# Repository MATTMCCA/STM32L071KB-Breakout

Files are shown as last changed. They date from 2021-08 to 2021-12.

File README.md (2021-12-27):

# STM32L071KB-Breakout
 STM32L071KB Breakout/Eval Board & STLink V2 adapter.
 
*Was quickly thrown together to further private works.*

**Gerbers meet JLC design spec**
 
 ## BOM
* EVAL 

[Digikey Cart Share](https://www.digikey.com/short/h47hrp48)

[Board](https://oshpark.com/shared_projects/n7sNnrIe)

* PROG 

[Digikey Cart Share](https://www.digikey.com/short/nmdddnm9)

[Board](https://oshpark.com/shared_projects/kYvOD2Zq)

---
### Captains Log (star date.. too cloudy, can't tell)

Boards came back from fab, they look good, just waiting on parts....

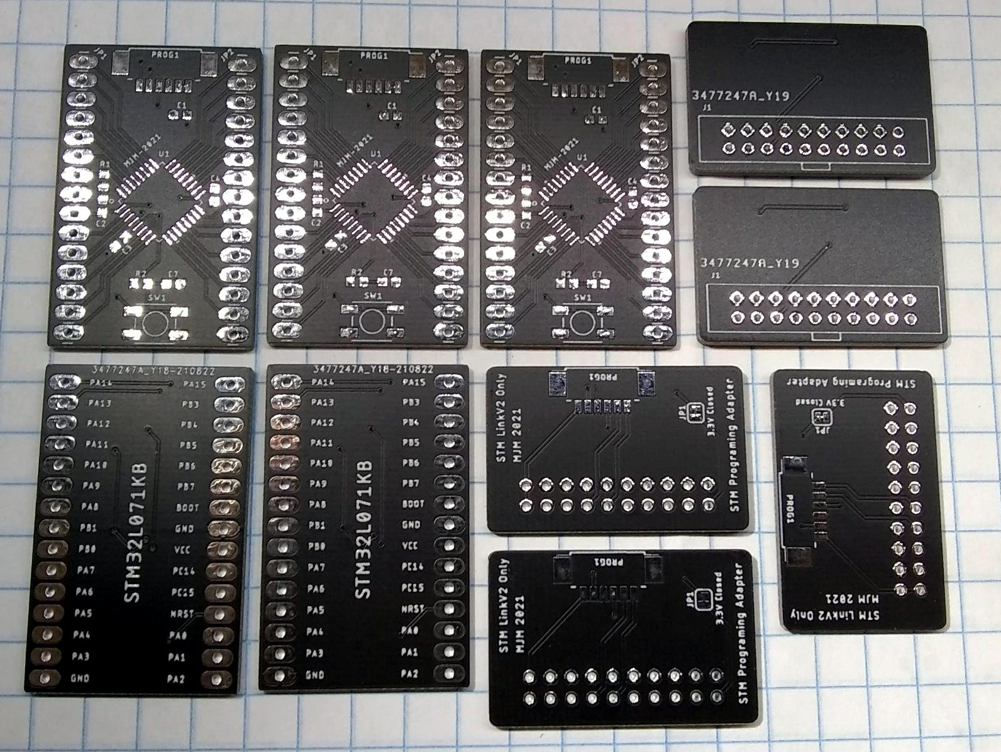
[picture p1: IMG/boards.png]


Parts came today, everything's working just fine.

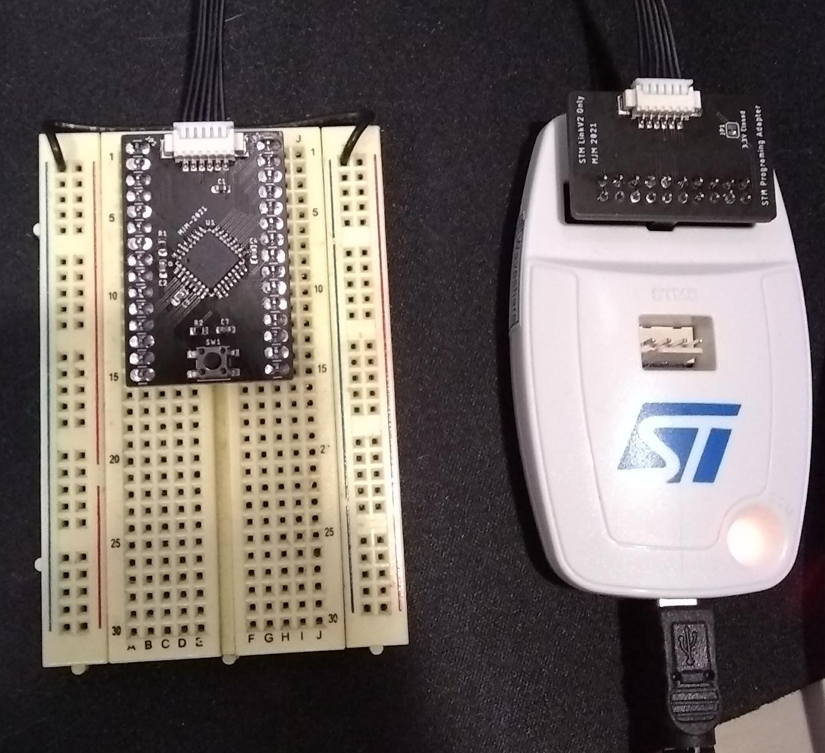
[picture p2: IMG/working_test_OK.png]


### Borrowed works maintain original license.

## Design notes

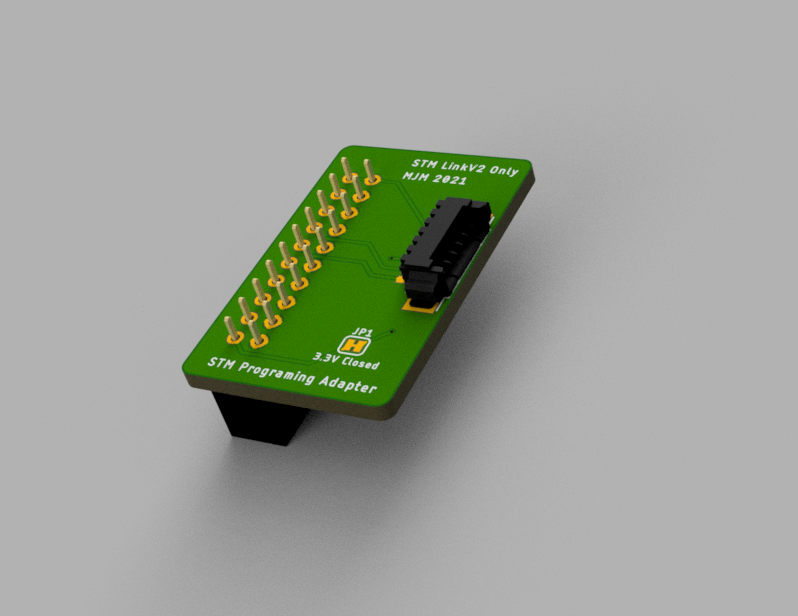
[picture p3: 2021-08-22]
Hardware/prog-adapter/render/adapter v2.png

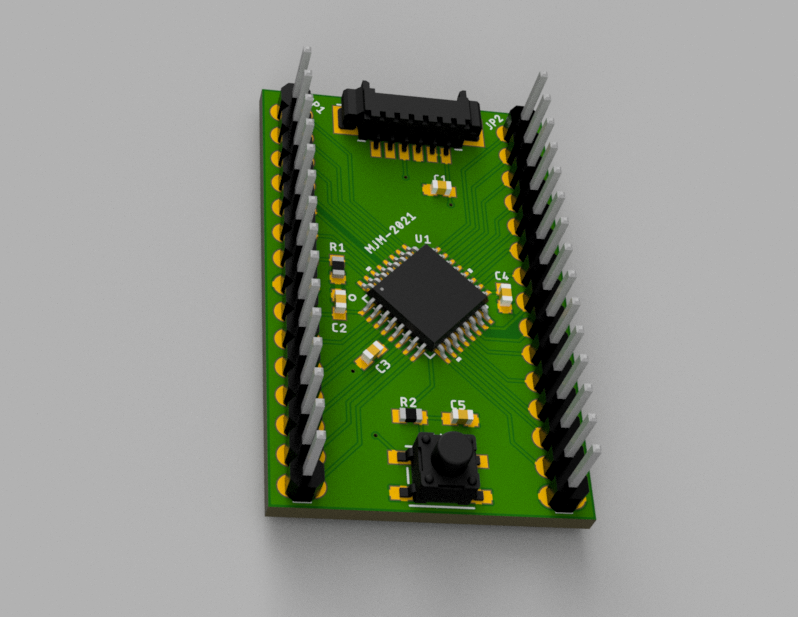
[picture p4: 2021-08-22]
Hardware/eval/render/Eval v1.png

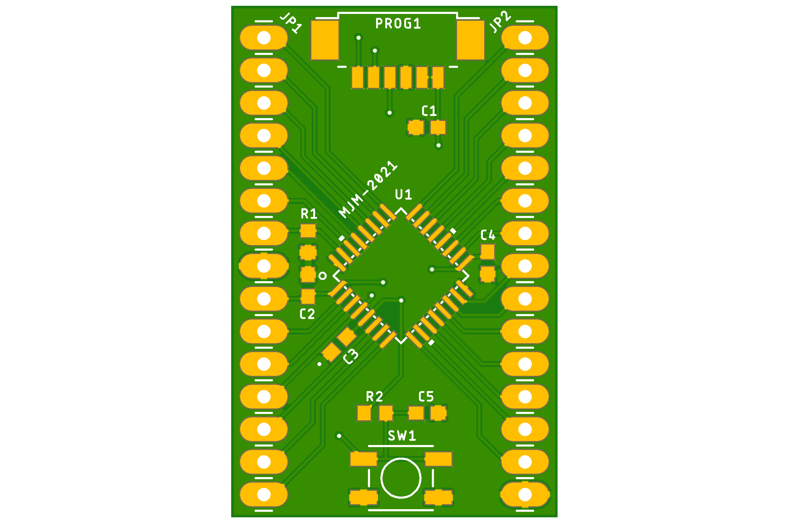
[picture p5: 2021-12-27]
Hardware/eval/brd/top.png

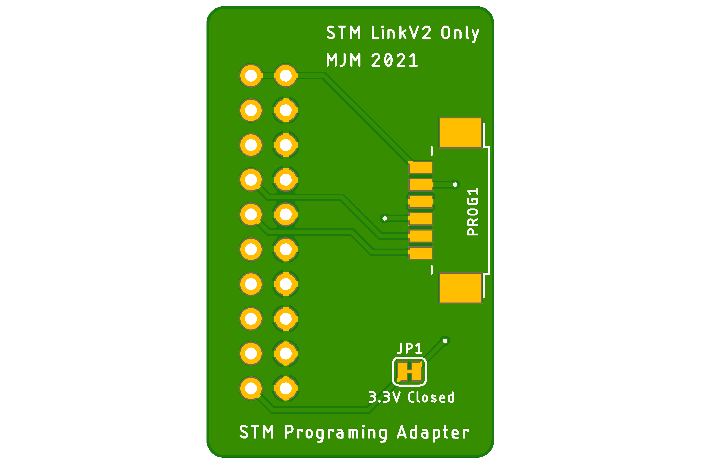
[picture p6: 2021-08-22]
Hardware/prog-adapter/brd/top.png

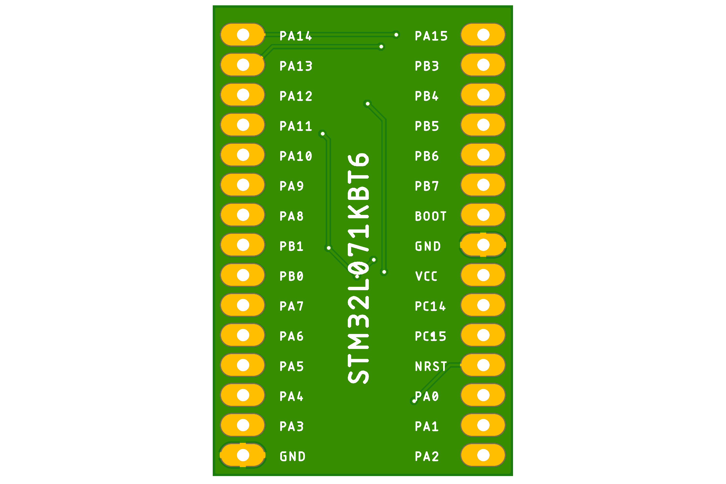
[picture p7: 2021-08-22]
Hardware/eval/brd/bot.png

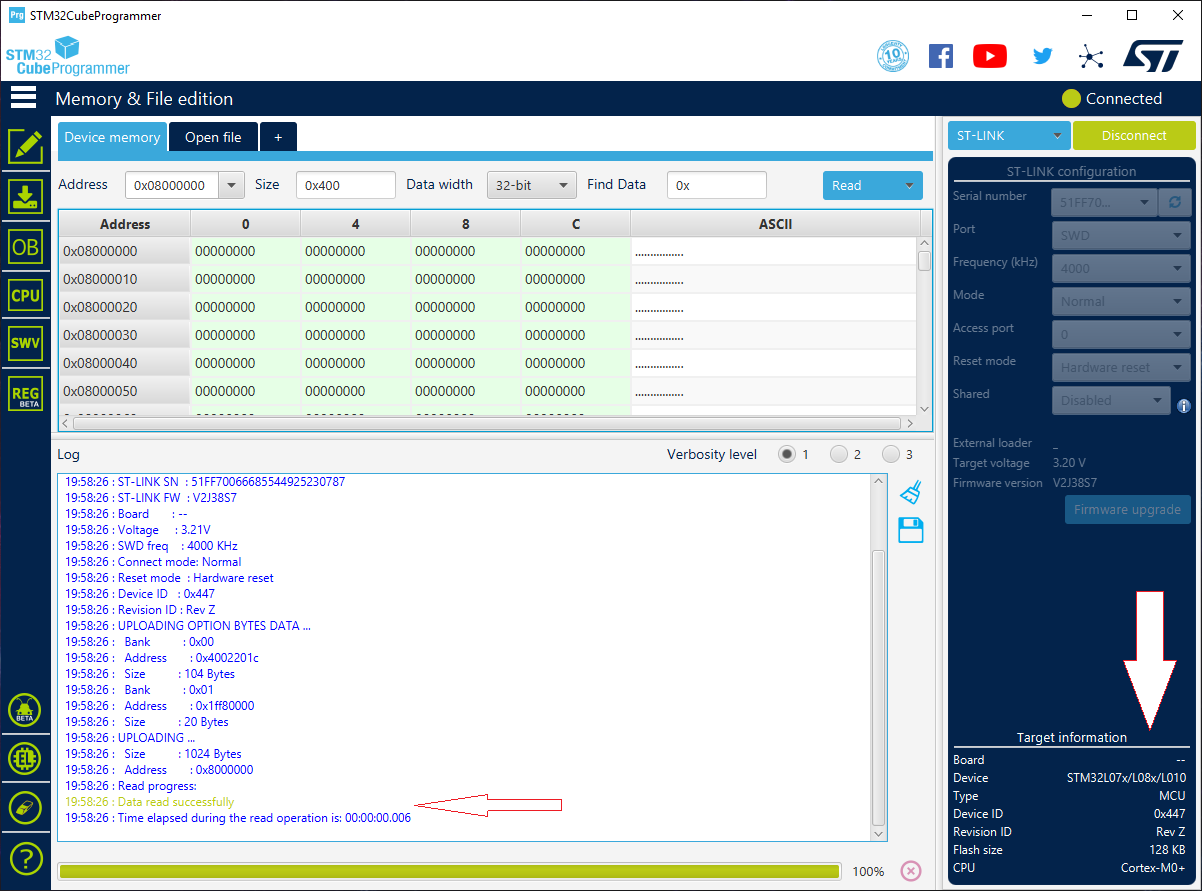
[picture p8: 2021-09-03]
IMG/chip_check-post.png

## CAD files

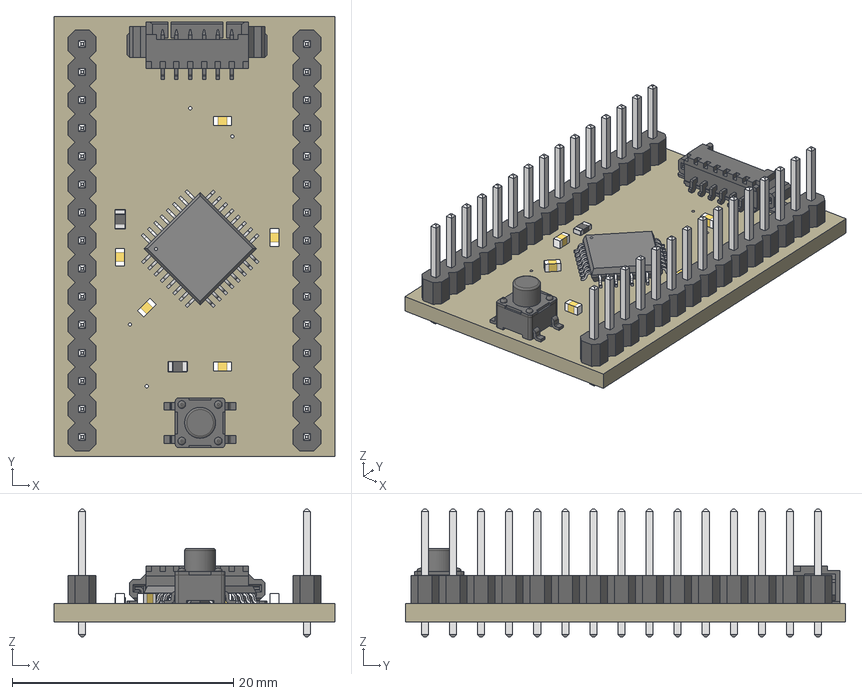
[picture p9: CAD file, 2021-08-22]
Hardware/eval/render/Eval.step
25.4 x 39.8 x 11.5 mm
Board
1uF x 5
100k x 2
PTS
STM32L071KBT6
1X15 x 2

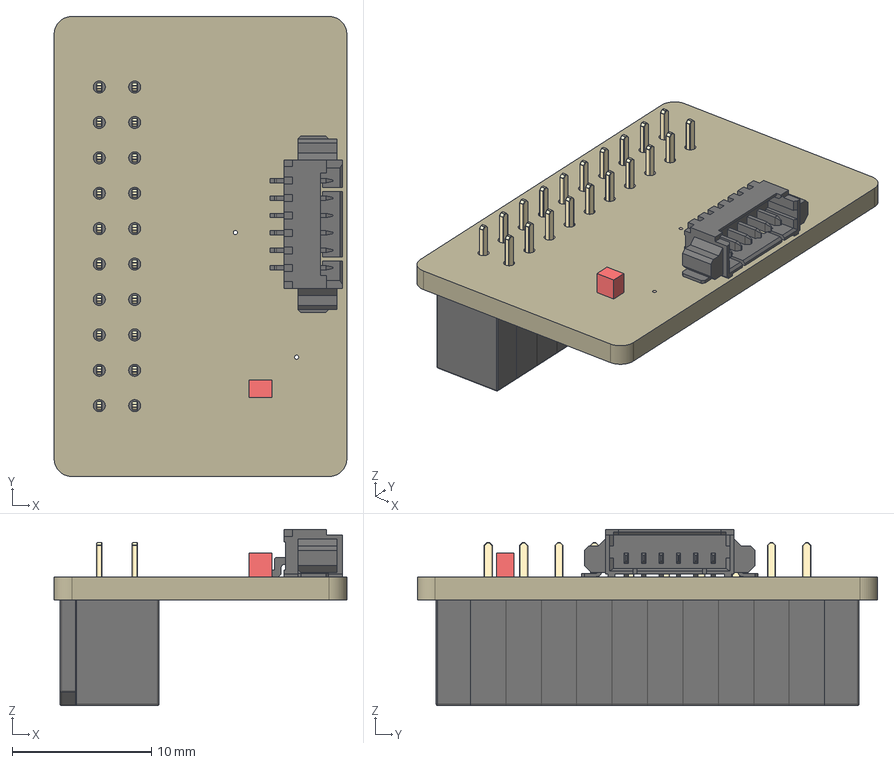
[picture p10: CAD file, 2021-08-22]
Hardware/prog-adapter/render/adapter.step
21.0 x 33.0 x 12.6 mm
Board
body section with ST gold pins x 30
end x 2
Polarizing Key
JMP

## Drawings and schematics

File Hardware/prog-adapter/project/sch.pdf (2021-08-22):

J1

Sheet: ABCD | 1 | 2 | 3 | 4 | 5 | 6 | ABCD 1 | 2 | 3 | 4 | 5 | 6

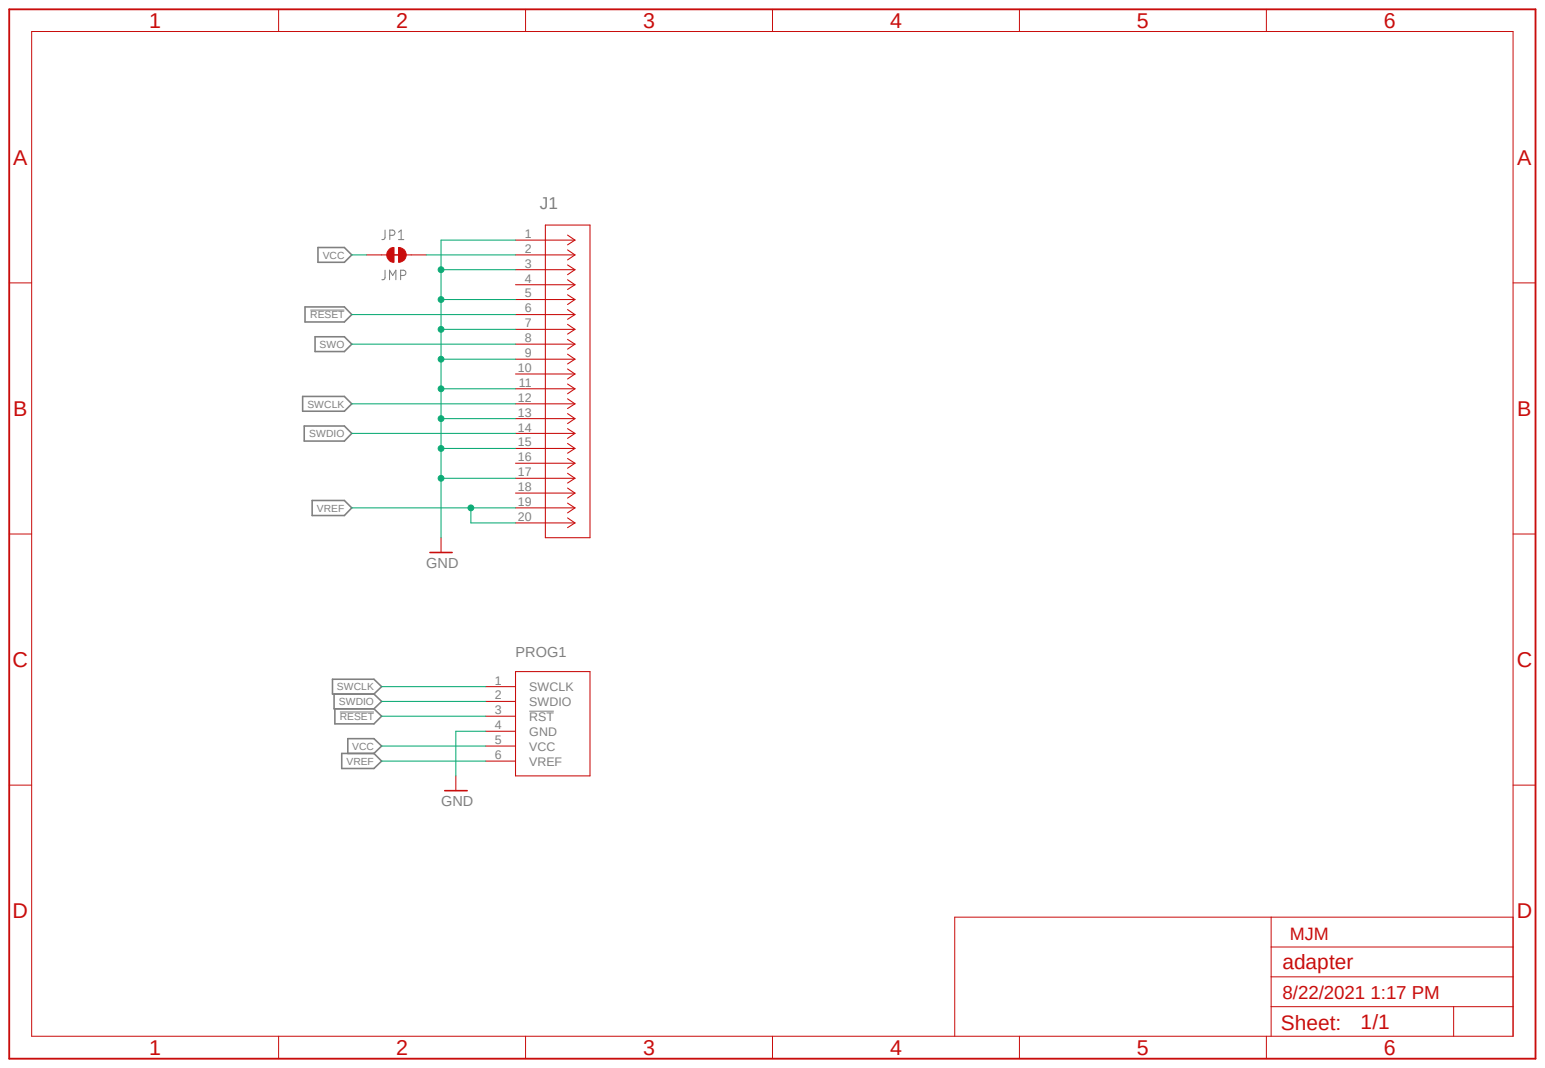
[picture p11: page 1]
GND; SWCLK; SWDIO; RST; VCC; VREF; 6 PROG1; RESET; SWO; MJM; adapter

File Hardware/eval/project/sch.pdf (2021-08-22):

## STM32L071KBT6

A

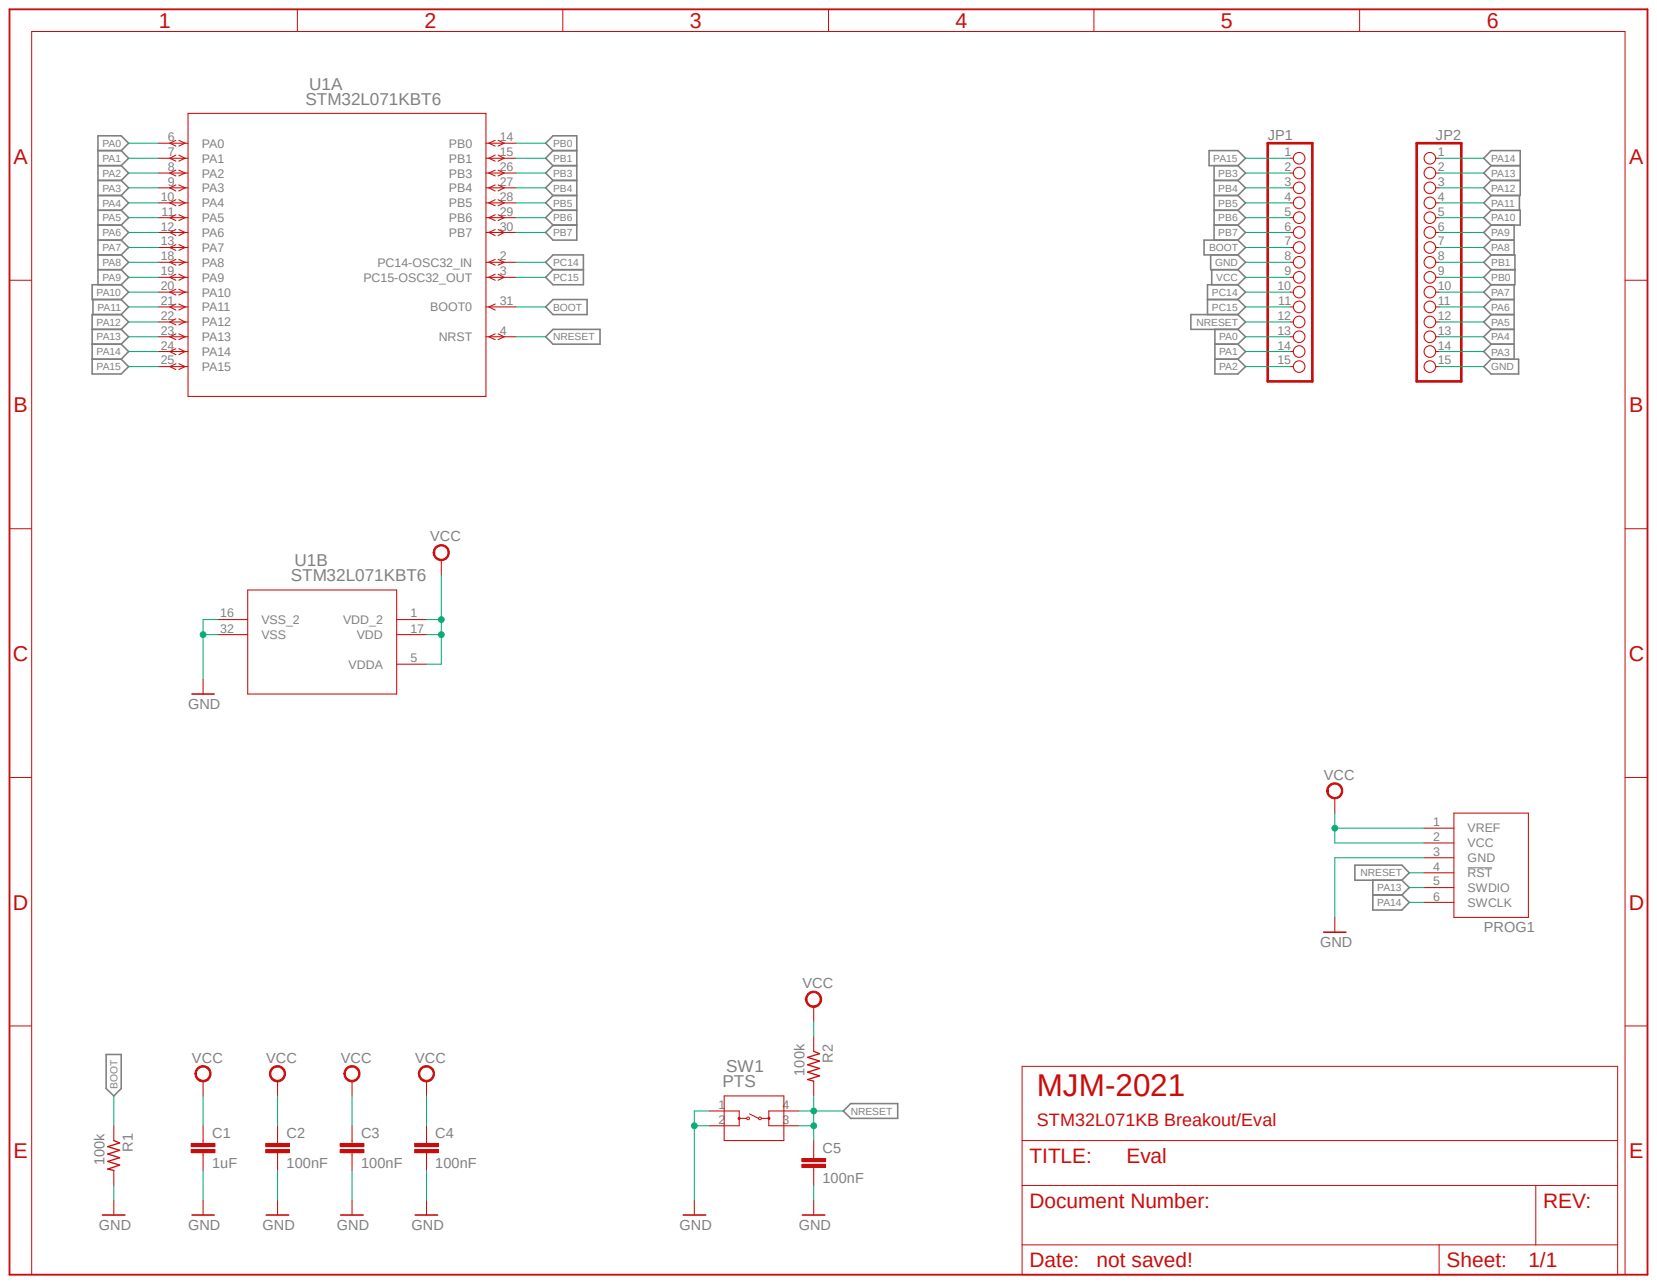
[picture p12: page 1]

Document Number: | REV:

Date: not saved! | Sheet: 1/1

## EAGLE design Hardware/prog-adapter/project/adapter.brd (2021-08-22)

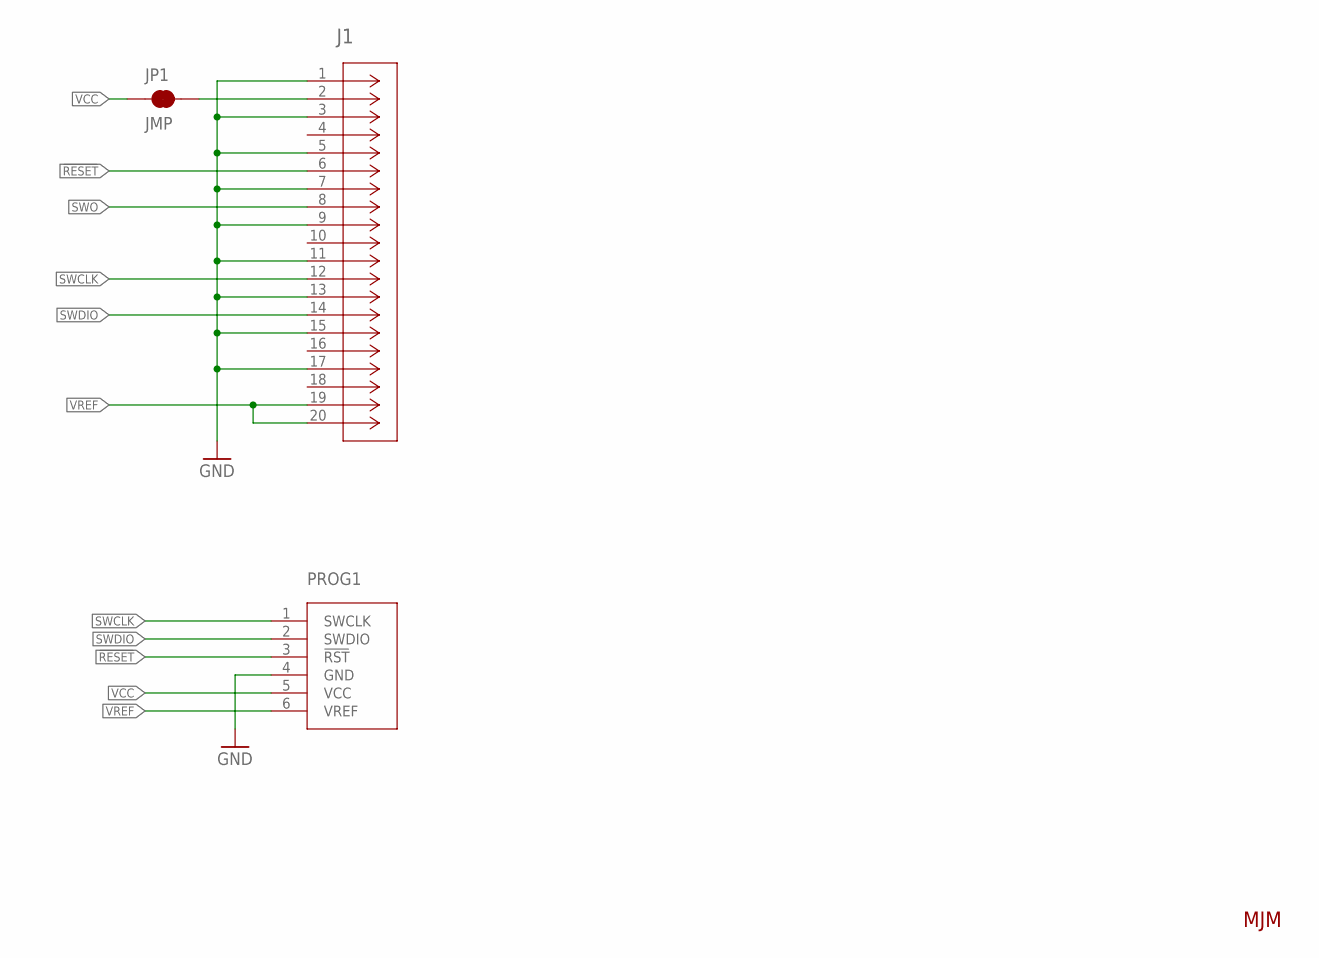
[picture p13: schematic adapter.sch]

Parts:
J1: SFH11-PBPC-D10-ST-BK; CONN_SFH11-PBPC-D10-ST-BK_SUL
JP1: JMP; SMT-JUMPER_2_NC_TRACE_SILK
PROG1: 0532610671_OP; 0532610671

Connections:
!RESET: J1.6, PROG1.3 (!RST)
GND: J1.1, J1.3, J1.5, J1.7, J1.9, J1.11, J1.13, J1.15, J1.17, PROG1.4 (GND)
unnamed: J1.2, JP1.2
SWCLK: J1.12, PROG1.1 (SWCLK)
SWDIO: J1.14, PROG1.2 (SWDIO)
SWO: J1.8
VCC: JP1.1, PROG1.5 (VCC)
VREF: J1.19, J1.20, PROG1.6 (VREF)

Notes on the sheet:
MJM

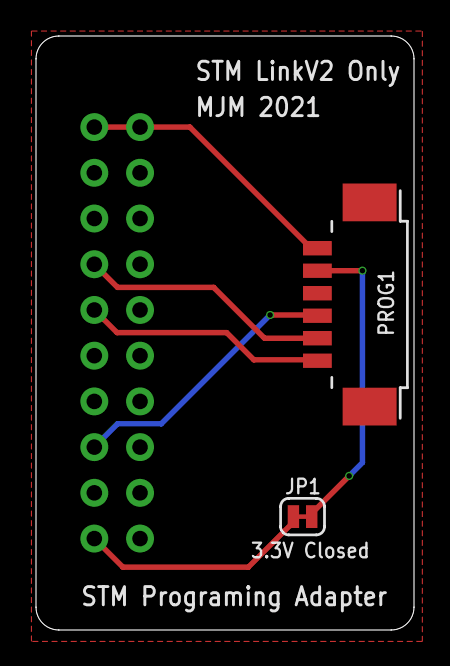
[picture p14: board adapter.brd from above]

Board: 2 copper layers, 21.0 x 33.0 mm, 3 parts (1 on the bottom side), 7 nets.

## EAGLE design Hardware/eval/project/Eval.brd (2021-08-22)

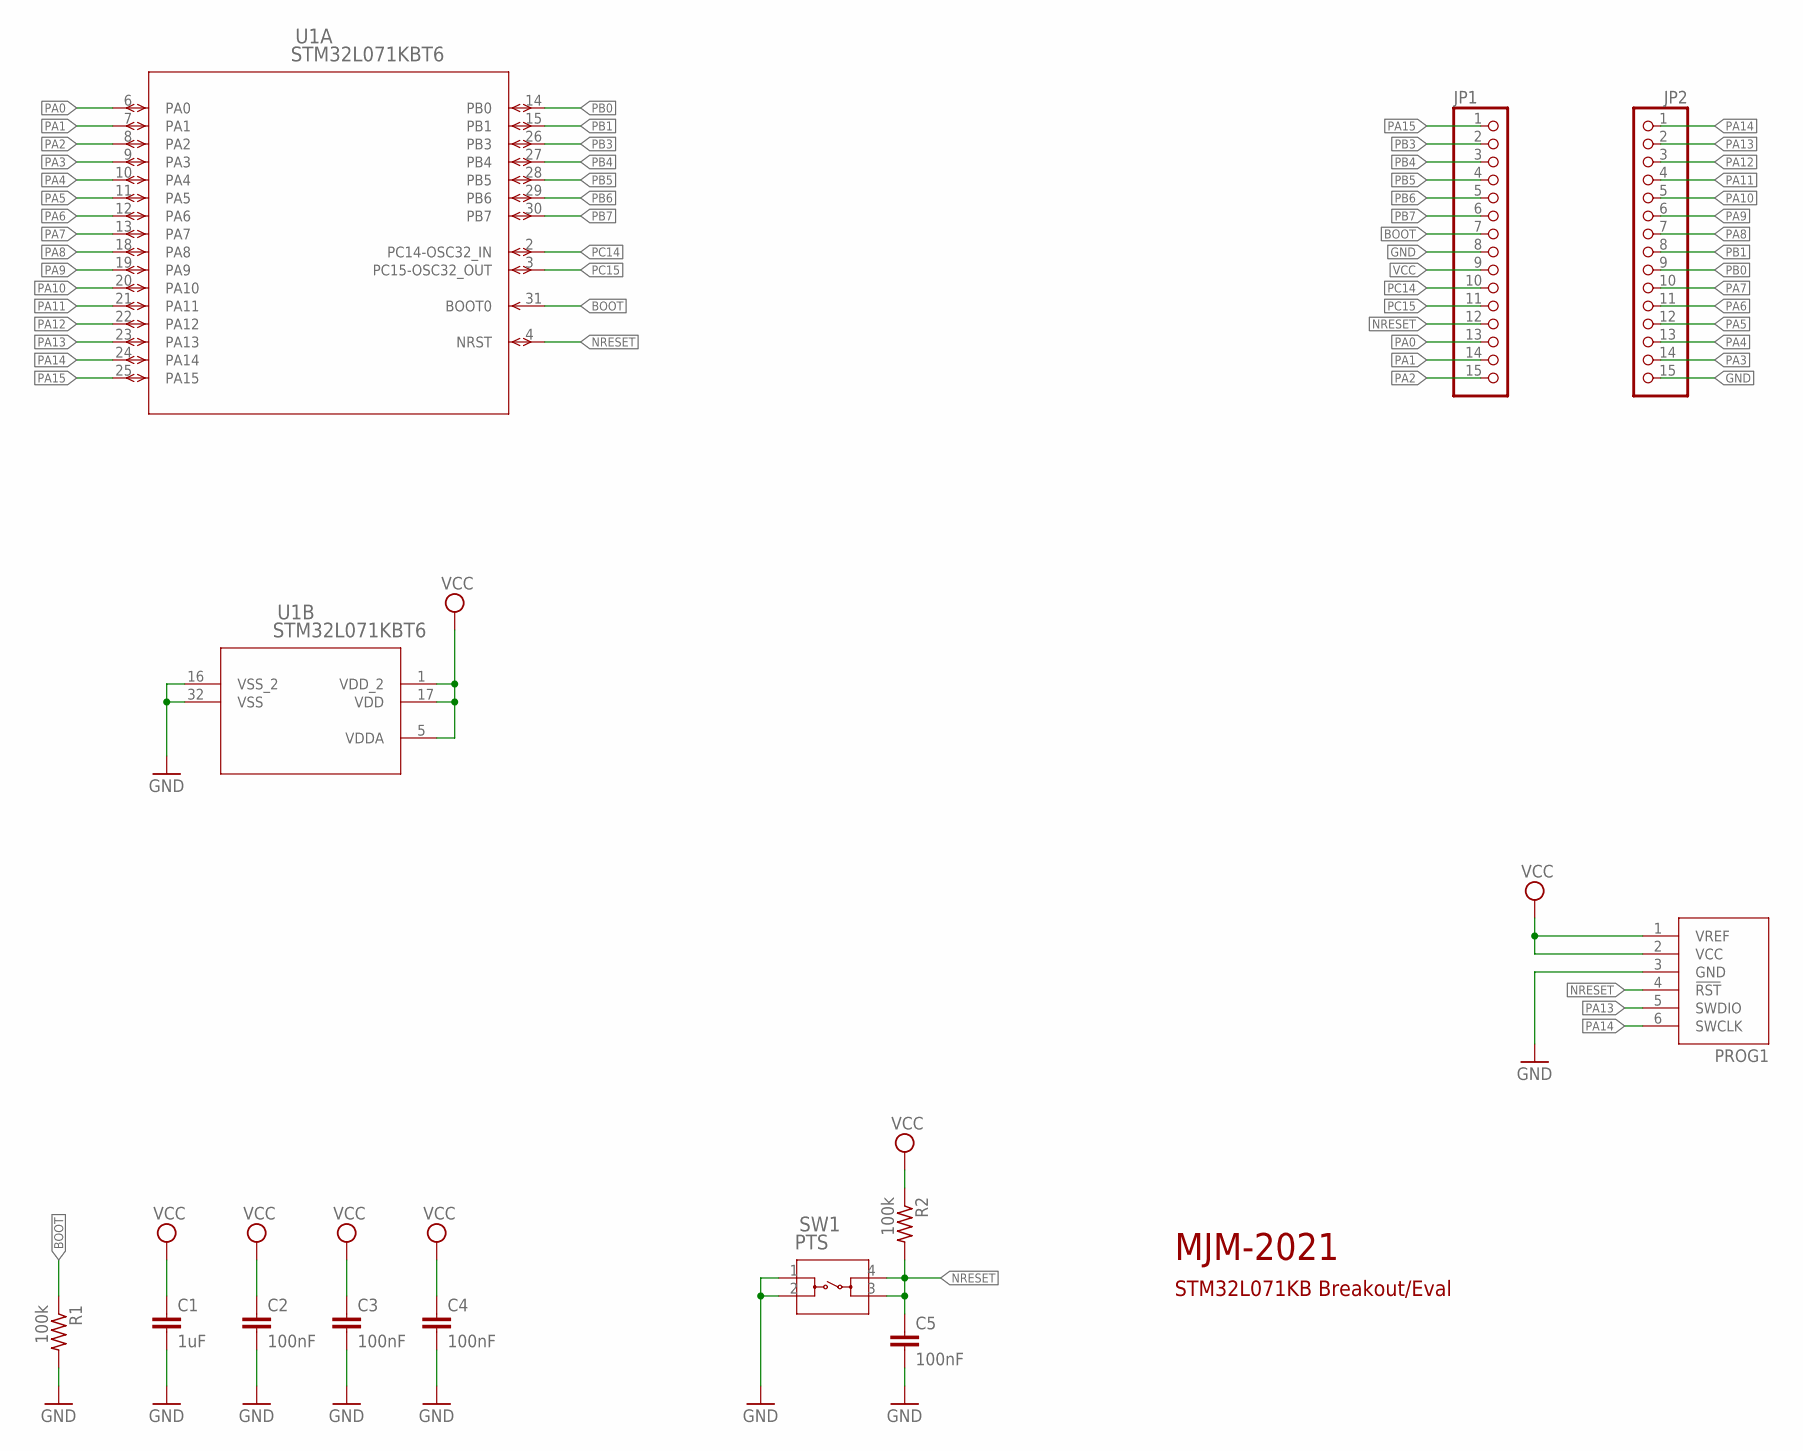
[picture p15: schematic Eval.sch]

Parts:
C1: 1uF; C0603
C2, C3, C4, C5: 100nF; C0603
JP1, JP2: PINHD-1X15; 1X15
PROG1: 0532610671
R1, R2: 100k; R0603
SW1: PTS; PTS_647_SN50_SMTR2_LFS-M
U1: STM32L071KBT6; LQFP32_7X7X1P4

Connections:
BOOT: JP1.7, R1.1, U1.31 (BOOT0)
GND: C1.2, C2.2, C3.2, C4.2, C5.2, JP1.8, JP2.15, PROG1.3 (GND), R1.2, SW1.1, SW1.2, U1.16 (VSS_2), U1.32 (VSS)
NRESET: C5.1, JP1.12, PROG1.4 (!RST), R2.2, SW1.3, SW1.4, U1.4 (NRST)
PA0: JP1.13, U1.6 (PA0)
PA1: JP1.14, U1.7 (PA1)
PA2: JP1.15, U1.8 (PA2)
PA3: JP2.14, U1.9 (PA3)
PA4: JP2.13, U1.10 (PA4)
PA5: JP2.12, U1.11 (PA5)
PA6: JP2.11, U1.12 (PA6)
PA7: JP2.10, U1.13 (PA7)
PA8: JP2.7, U1.18 (PA8)
PA9: JP2.6, U1.19 (PA9)
PA10: JP2.5, U1.20 (PA10)
PA11: JP2.4, U1.21 (PA11)
PA12: JP2.3, U1.22 (PA12)
PA13: JP2.2, PROG1.5 (SWDIO), U1.23 (PA13)
PA14: JP2.1, PROG1.6 (SWCLK), U1.24 (PA14)
PA15: JP1.1, U1.25 (PA15)
PB0: JP2.9, U1.14 (PB0)
PB1: JP2.8, U1.15 (PB1)
PB3: JP1.2, U1.26 (PB3)
PB4: JP1.3, U1.27 (PB4)
PB5: JP1.4, U1.28 (PB5)
PB6: JP1.5, U1.29 (PB6)
PB7: JP1.6, U1.30 (PB7)
PC14: JP1.10, U1.2 (PC14-OSC32_IN)
PC15: JP1.11, U1.3 (PC15-OSC32_OUT)
VCC: C1.1, C2.1, C3.1, C4.1, JP1.9, PROG1.1 (VREF), PROG1.2 (VCC), R2.1, U1.1 (VDD_2), U1.5 (VDDA), U1.17 (VDD)

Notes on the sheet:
MJM-2021
STM32L071KB Breakout/Eval

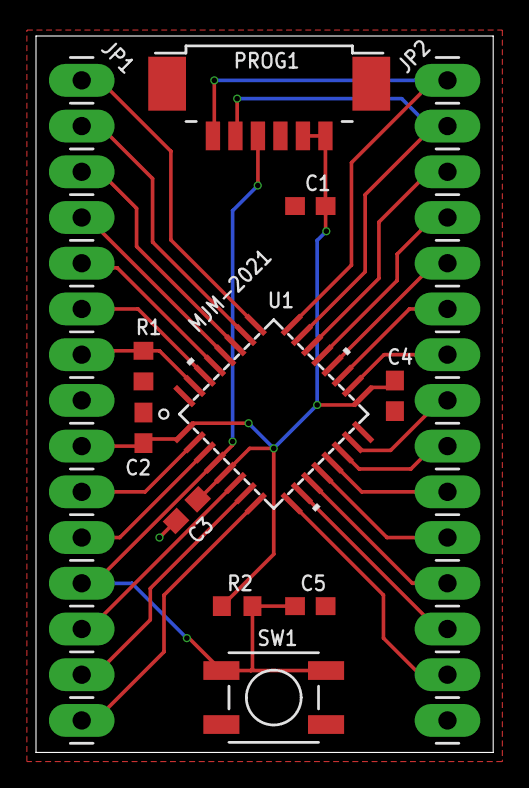
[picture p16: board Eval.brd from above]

Board: 2 copper layers, 25.4 x 39.8 mm, 12 parts (0 on the bottom side), 29 nets.

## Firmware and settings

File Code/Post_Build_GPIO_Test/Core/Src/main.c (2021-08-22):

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
/* Includes ------------------------------------------------------------------*/
#include "main.h"
#include "gpio.h"

/* USER CODE BEGIN PTD */

typedef struct {
	GPIO_TypeDef *GPIOx;
	uint16_t GPIO_Pin;
} pinmap;

/* USER CODE END PTD */


void SystemClock_Config(void);
/**
  * @brief  The application entry point.
  * @retval int
  */
int main(void)
{
  /* MCU Configuration--------------------------------------------------------*/

  /* Reset of all peripherals, Initializes the Flash interface and the Systick. */
  HAL_Init();

  /* Configure the system clock */
  SystemClock_Config();

  /* Initialize all configured peripherals */
  MX_GPIO_Init();
  /* USER CODE BEGIN 2 */


  /* TEST GPIO STRUCT ARRAY */
  pinmap pm[23] =
  {
	  {PIN_PA0_GPIO_Port,  PIN_PA0_Pin},
	  {PIN_PA1_GPIO_Port,  PIN_PA1_Pin},
	  {PIN_PA2_GPIO_Port,  PIN_PA2_Pin},
	  {PIN_PA3_GPIO_Port,  PIN_PA3_Pin},
	  {PIN_PA4_GPIO_Port,  PIN_PA4_Pin},
	  {PIN_PA5_GPIO_Port,  PIN_PA5_Pin},
	  {PIN_PA6_GPIO_Port,  PIN_PA6_Pin},
	  {PIN_PA7_GPIO_Port,  PIN_PA7_Pin},
	  {PIN_PA8_GPIO_Port,  PIN_PA8_Pin},
	  {PIN_PA9_GPIO_Port,  PIN_PA9_Pin},
	  {PIN_PA10_GPIO_Port, PIN_PA10_Pin},
	  {PIN_PA11_GPIO_Port, PIN_PA11_Pin},
	  {PIN_PA12_GPIO_Port, PIN_PA12_Pin},
	  //{PIN_PA13_GPIO_Port, PIN_PA13_Pin},
	  //{PIN_PA14_GPIO_Port, PIN_PA14_Pin},
	  {PIN_PA15_GPIO_Port, PIN_PA15_Pin},
	  {PIN_PB0_GPIO_Port,  PIN_PB0_Pin},
	  {PIN_PB1_GPIO_Port,  PIN_PB1_Pin},
	  {PIN_PB3_GPIO_Port,  PIN_PB3_Pin},
	  {PIN_PB4_GPIO_Port,  PIN_PB4_Pin},
	  {PIN_PB5_GPIO_Port,  PIN_PB5_Pin},
	  {PIN_PB6_GPIO_Port,  PIN_PB6_Pin},
	  {PIN_PB7_GPIO_Port,  PIN_PB7_Pin},
	  {PIN_PC14_GPIO_Port, PIN_PC14_Pin},
	  {PIN_PC15_GPIO_Port, PIN_PC15_Pin},
  };

  /* USER CODE END 2 */

  /* Infinite loop */
  /* USER CODE BEGIN WHILE */
  while (1)
  {
    /* USER CODE END WHILE */

    /* USER CODE BEGIN 3 */

	  for(int i = 0; i < 23; i++) {
		  HAL_GPIO_TogglePin(pm[i].GPIOx, pm[i].GPIO_Pin); //should toggle all pins forever
		  __NOP(); //add breakpoint
	  }

  }
  /* USER CODE END 3 */
}

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


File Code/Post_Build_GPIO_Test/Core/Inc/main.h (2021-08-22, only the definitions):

#define PIN_PC14_Pin GPIO_PIN_14
#define PIN_PC14_GPIO_Port GPIOC
#define PIN_PC15_Pin GPIO_PIN_15
#define PIN_PC15_GPIO_Port GPIOC
#define PIN_PA0_Pin GPIO_PIN_0
#define PIN_PA0_GPIO_Port GPIOA
#define PIN_PA1_Pin GPIO_PIN_1
#define PIN_PA1_GPIO_Port GPIOA
#define PIN_PA2_Pin GPIO_PIN_2
#define PIN_PA2_GPIO_Port GPIOA
#define PIN_PA3_Pin GPIO_PIN_3
#define PIN_PA3_GPIO_Port GPIOA
#define PIN_PA4_Pin GPIO_PIN_4
#define PIN_PA4_GPIO_Port GPIOA
#define PIN_PA5_Pin GPIO_PIN_5
#define PIN_PA5_GPIO_Port GPIOA
#define PIN_PA6_Pin GPIO_PIN_6
#define PIN_PA6_GPIO_Port GPIOA
#define PIN_PA7_Pin GPIO_PIN_7
#define PIN_PA7_GPIO_Port GPIOA
#define PIN_PB0_Pin GPIO_PIN_0
#define PIN_PB0_GPIO_Port GPIOB
#define PIN_PB1_Pin GPIO_PIN_1
#define PIN_PB1_GPIO_Port GPIOB
#define PIN_PA8_Pin GPIO_PIN_8
#define PIN_PA8_GPIO_Port GPIOA
#define PIN_PA9_Pin GPIO_PIN_9
#define PIN_PA9_GPIO_Port GPIOA
#define PIN_PA10_Pin GPIO_PIN_10
#define PIN_PA10_GPIO_Port GPIOA
#define PIN_PA11_Pin GPIO_PIN_11
#define PIN_PA11_GPIO_Port GPIOA
#define PIN_PA12_Pin GPIO_PIN_12
#define PIN_PA12_GPIO_Port GPIOA
#define PIN_PA15_Pin GPIO_PIN_15
#define PIN_PA15_GPIO_Port GPIOA
#define PIN_PB3_Pin GPIO_PIN_3
#define PIN_PB3_GPIO_Port GPIOB
#define PIN_PB4_Pin GPIO_PIN_4
#define PIN_PB4_GPIO_Port GPIOB
#define PIN_PB5_Pin GPIO_PIN_5
#define PIN_PB5_GPIO_Port GPIOB
#define PIN_PB6_Pin GPIO_PIN_6
#define PIN_PB6_GPIO_Port GPIOB
#define PIN_PB7_Pin GPIO_PIN_7
#define PIN_PB7_GPIO_Port GPIOB

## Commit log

2021-08-22 added adapter board
    Changed repo struct.
    Added prog_adapter.
    [Eval.brd, Eval.sch, adapter.brd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]
2021-08-22 step upload
    [Eval.step, adapter.step]
2021-08-22 GPIO TEST
    Post assembly GPIO Test Code.
2021-08-22 enabled single wire debugging on pa13 & pa14

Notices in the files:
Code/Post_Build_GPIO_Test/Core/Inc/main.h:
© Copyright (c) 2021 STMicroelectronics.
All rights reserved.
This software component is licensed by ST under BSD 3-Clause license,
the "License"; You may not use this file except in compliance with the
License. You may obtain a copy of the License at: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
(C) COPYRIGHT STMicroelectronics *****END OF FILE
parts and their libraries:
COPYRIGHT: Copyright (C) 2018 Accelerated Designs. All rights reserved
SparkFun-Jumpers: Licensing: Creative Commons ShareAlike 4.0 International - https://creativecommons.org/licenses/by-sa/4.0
